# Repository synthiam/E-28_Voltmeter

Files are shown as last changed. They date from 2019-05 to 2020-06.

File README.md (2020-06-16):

# E-28 Voltmeter

**Project Status:** Ready to manufacture

If you are new to GitHub and would like to create a derivative of this project, please have a look at GitHub instructions to [fork a repo](https://help.github.com/en/articles/fork-a-repo)

## Description

Out of our passion to solve the issue of time waste in the robot creation process, ARC was born. The ARC software platform reduces the time it takes to get from idea to implementation. Since 2011 we have been listening to the challenges robot builders encounter and continue to provide them with an ever expanding toolbox of solutions. Join us on this journey!

We didn't stop at the software, we also made time saving hardware solutions. This Voltmeter reference design is one of them. The Voltmeter connects to an ADC port. An ARC ADC skill can take the analog data and convert it into voltage in order to measure the source voltage of a supply or signal. A unique feature of this design is that it has reverse polarity protection. We want to share these files with you so you can create your own version for your community and customers to enjoy!

**Features:** 
- Multimeter Lead input with Flexible silicone wire
- Reverse polarity protection
- PCB can alternately be used with Banana Jacks
- Green Power LED
- Voltage requirement: 0-17.5VDC input
- Wire Length: 34"
- Dimensions: 26.3(W) x 30.8(L) x 9.2(H) (mm) PCB
- Weight: 58g

**Major components:** 
- D2275 Set of Multimeter probes
- 1N4448W-TP 75V 250mA reverse polarity Diode (low leakage current)

**Manufacturing notes:** 
1. Manufacturer: Single side placement and soldering of SMT components
2. Manufacturer: Single Side soldering of THT components

## Contents

[**Documentation:**](https://github.com/synthiam/E-28_Voltmeter/tree/master/E-28%20Documentation) Schematic PDF, BOM

[**Hardware:**](https://github.com/synthiam/E-28_Voltmeter/tree/master/E-28%20Hardware) Altium PCB design File, Altium SCH Design File, Gerbers

*Altium Libraries are also available <a href="https://github.com/synthiam/Synthiam_Altium_Librairies">here</a>*

## Photos

<p align="left">

</p>

## Roll Out Video

This Roll Out video includes:

1. Feature set 
2. Hook-up guide 
3. Using ARC Skills
4. Schematic overview
5. Bill of Materials (BOM) overview
6. Assembly instructions

Link: https://youtu.be/czC40y7L5Ys

 

## ARC Skill

The ARC ADC skills are very easy to use with the Voltmeter. Read or graph the voltage values with the simple click of a mouse button or with code. 

Link: https://synthiam.com/Products/Controls/Adc



## Contact

For profit use of these files requires written consent. Contact partners@synthiam.com. For everyone else, party on!

For support check out our Synthiam Community: https://synthiam.com/Community

## License

This project is released under the following license:

**Hardware:** Creative Commons Plus Attribution-NonCommercial 4.0 International (CC+ BY-NC 4.0)

Please see [LICENSE.md](https://github.com/synthiam/E-28_Voltmeter/blob/master/LICENSE.md) for license details.



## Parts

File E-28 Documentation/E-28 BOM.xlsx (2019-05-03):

Qty | Description | Manufacturer Part No. | Alternative | Designator | Custom Information | Link
E-28 Voltmeter
1 | 2 layer, Blue soldermask, White silkscreen, ENIG | Voltmeter Board |  | PCB
1 | 10Kohm 0603 Resistor 1% | RC0603FR-0710KL |  | R2
1 | 680ohm 0603 Resistor 1% | RC0603JR-07680RL |  | R1
1 | 2.4kohm 0603 Resistor 1% | RC0603FR-072K4L |  | R3
1 | 75V 250mA reverse polarity Diode SOD123 (low leakage current) | 1N4448W-TP |  | D1 |  | https://www.digikey.ca/product-detail/en/micro-commercial-co/1N4448W-TP/1N4448WTPMSCT-ND/789337
1 | Set of Multimeter probes | D2275 | F85 | P2, P3 | Banana connectors on probes need to be removed and wires directly soldered to board | https://www.alibaba.com/product-detail/Multimeter-Probe-DMM-Test-Probes-Multimetro_62021861221.html
1 | LED Green Clear 0805 | QBLP631-IG |  | LED
1 | 3 position 2.0mm pitch JST-PH header | S3B-PH-SM4-TB(LF)(SN) |  | P1 |  | https://www.digikey.ca/product-detail/en/jst-sales-america-inc/S3B-PH-SM4-TB-LF-SN/455-1750-1-ND/926847
4 | 8mm x 2.5mm self adhesive rubber feet (clear) |  |  |  | Placed on the bottom of the board in the 4 corners

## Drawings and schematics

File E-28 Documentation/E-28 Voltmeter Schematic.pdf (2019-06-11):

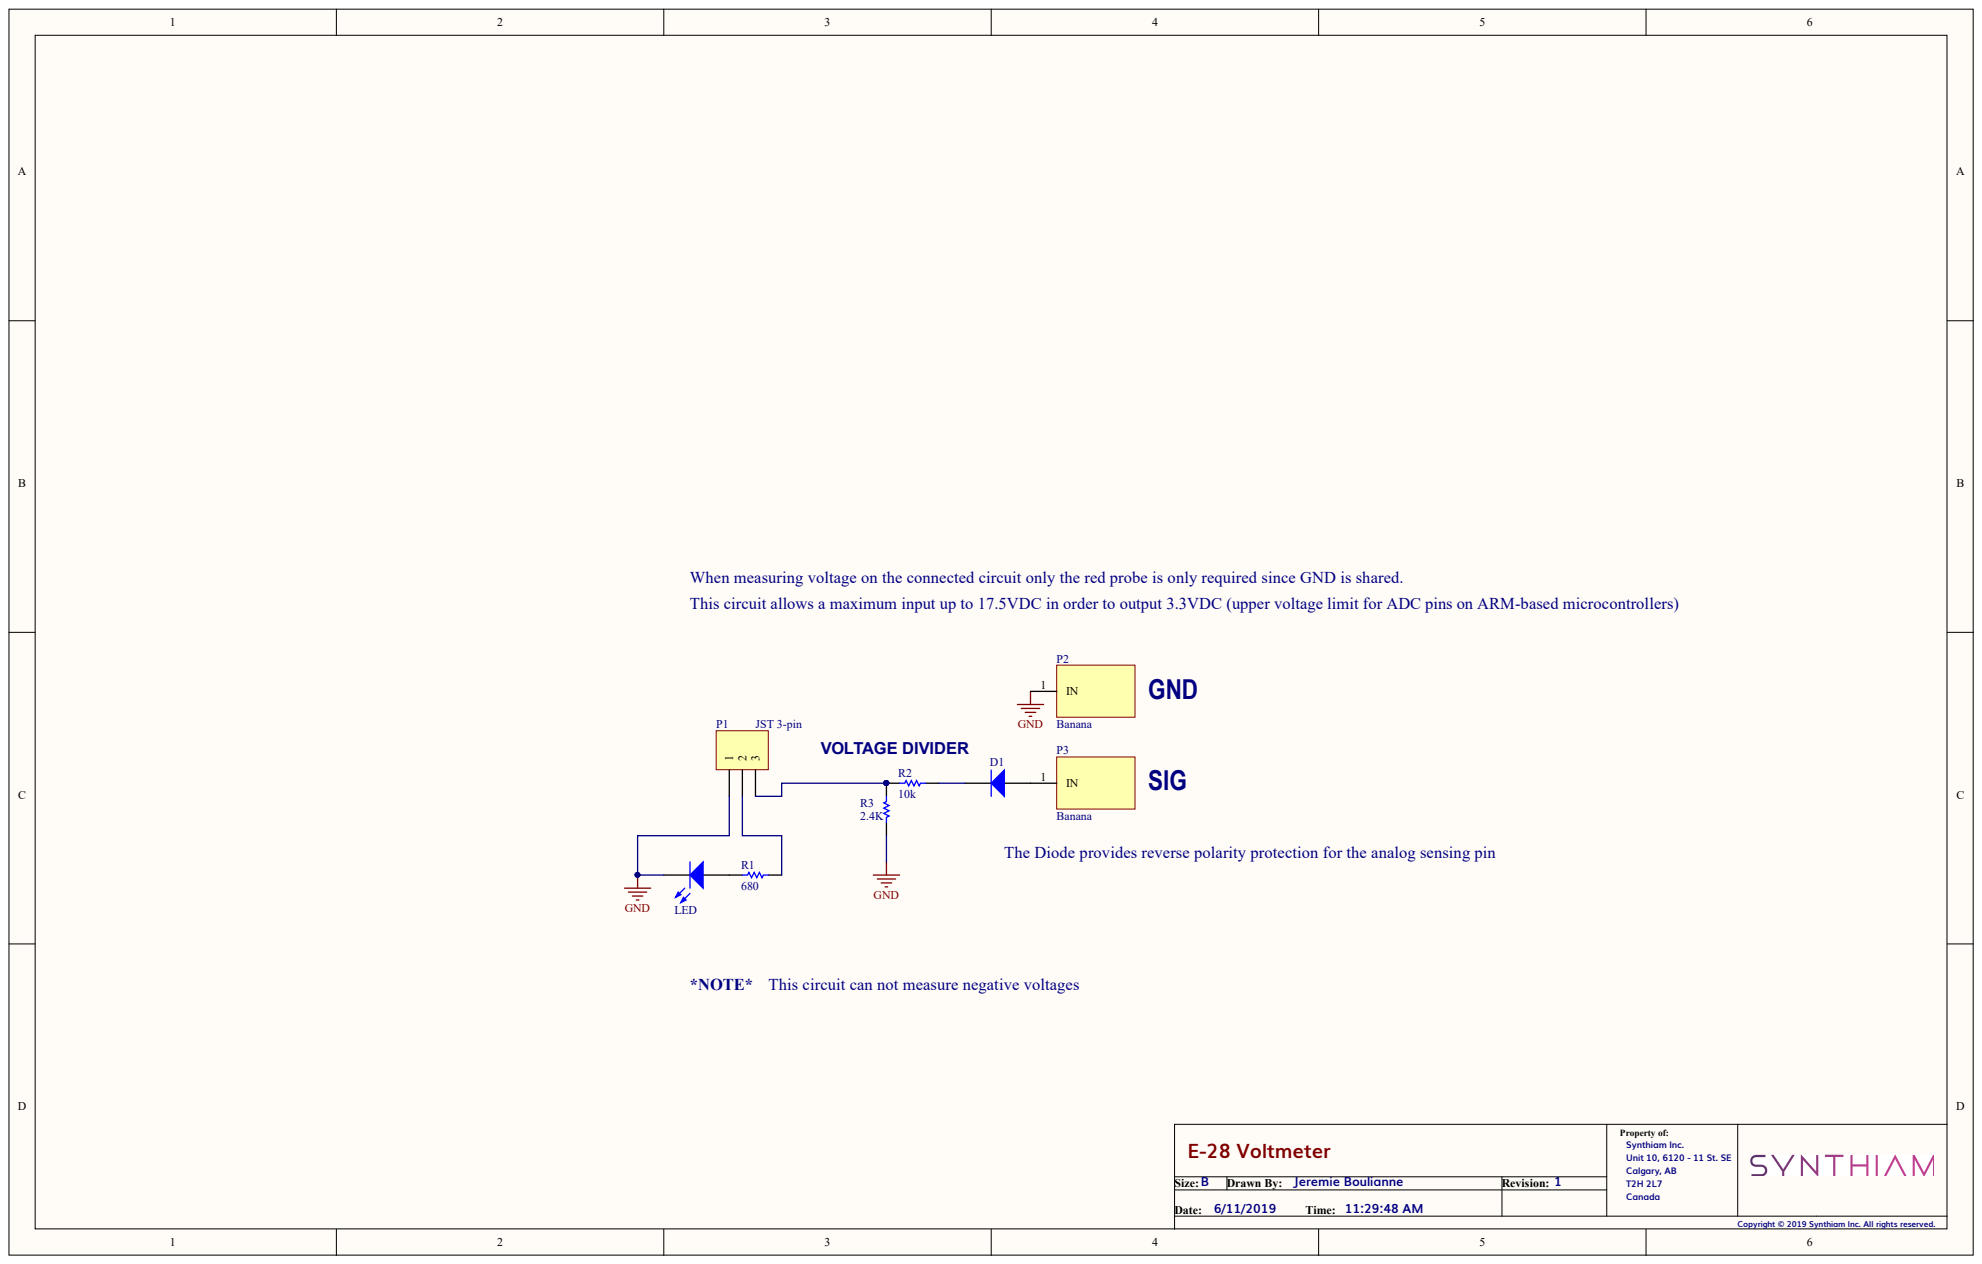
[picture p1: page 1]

When measuring voltage on the connected circuit only the red probe is only required since GND is shared.
This circuit allows a maximum input up to 17.5VDC in order to output 3.3VDC (upper voltage limit for ADC pins on ARM-based microcontrollers)

The Diode provides reverse polarity protection for the analog sensing pin

*NOTE* This circuit can not measure negative voltages

E-28 Voltmeter | Property of: Synthiam Inc. Unit 10, 6120 - 11 St. SE Calgary, AB T2H 2L7 Canada

B Size: | Jeremie Boulianne Drawn By: | 1 Revision:
6/11/2019 11:29:48 AM Date: Time:

Copyright © 2019 Synthiam Inc. All rights reserved.

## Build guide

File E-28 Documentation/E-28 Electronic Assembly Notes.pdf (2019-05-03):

# Electronic Assembly Notes

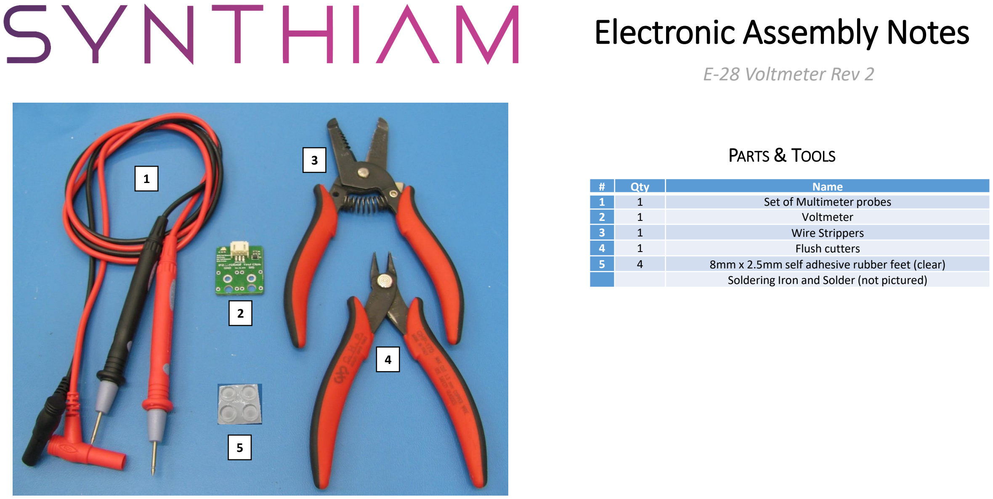
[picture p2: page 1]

# | Qty | Name

1 | 1 | Set of Multimeter probes
2 | 1 | Voltmeter
3 | 1 | Wire Strippers
4 | 1 | Flush cutters
5 | 4 | 8mm x 2.5mm self adhesive rubber feet (clear)
| | Soldering Iron and Solder (not pictured)

E-28 Voltmeter Rev 2

PARTS & TOOLS

1

2

3

4

5

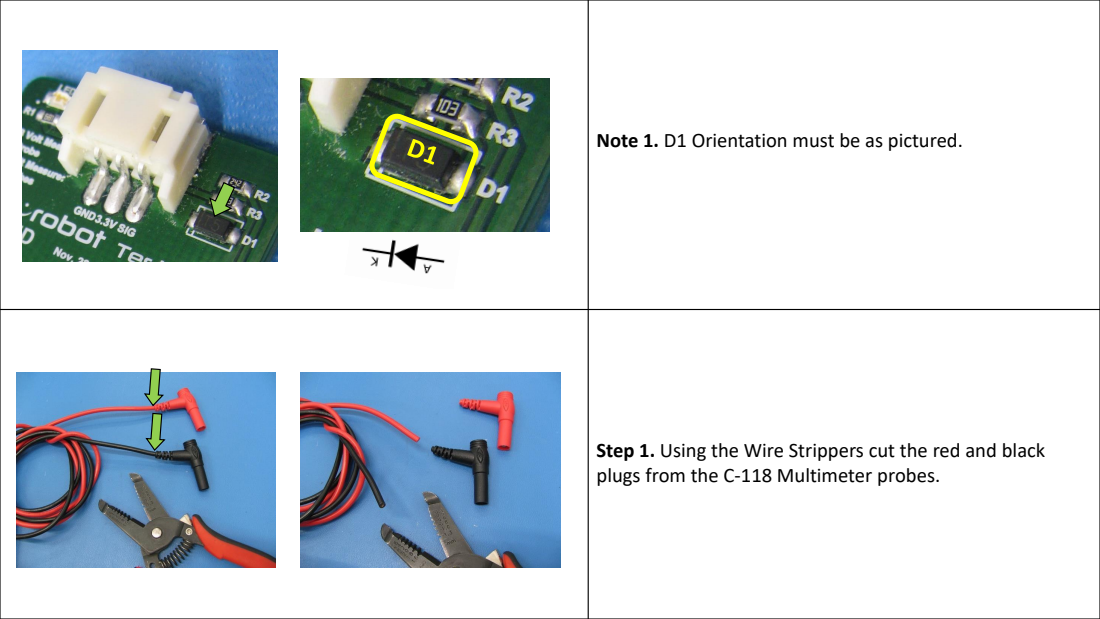
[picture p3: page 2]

Note 1. D1 Orientation must be as pictured.

Step 1. Using the Wire Strippers cut the red and black
plugs from the C-118 Multimeter probes.

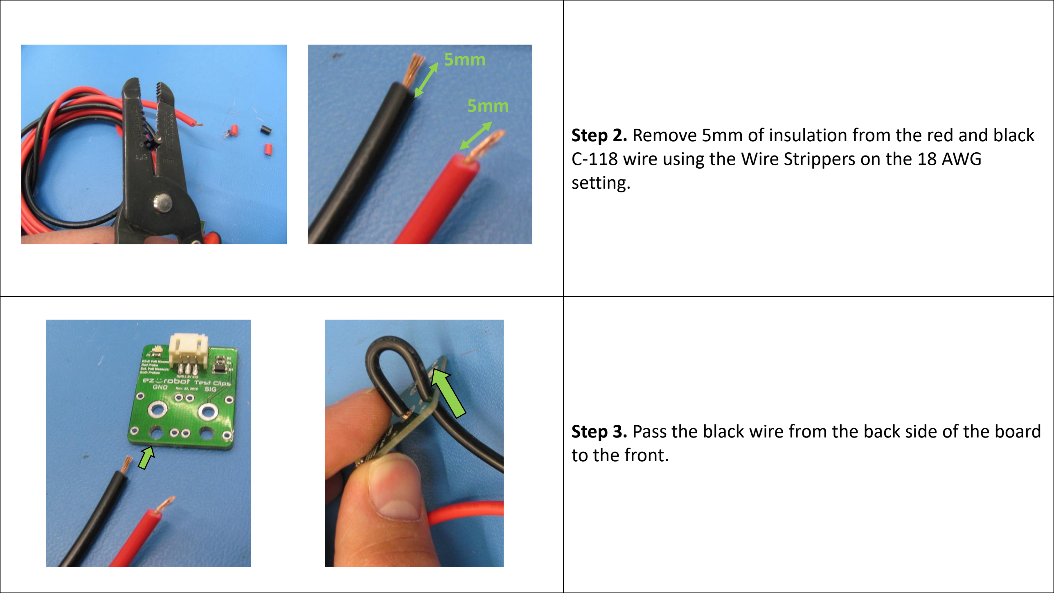
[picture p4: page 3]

Step 2. Remove 5mm of insulation from the red and black C-118 wire using the Wire Strippers on the 18 AWG setting.
Step 3. Pass the black wire from the back side of the board to the front.

5mm

5mm

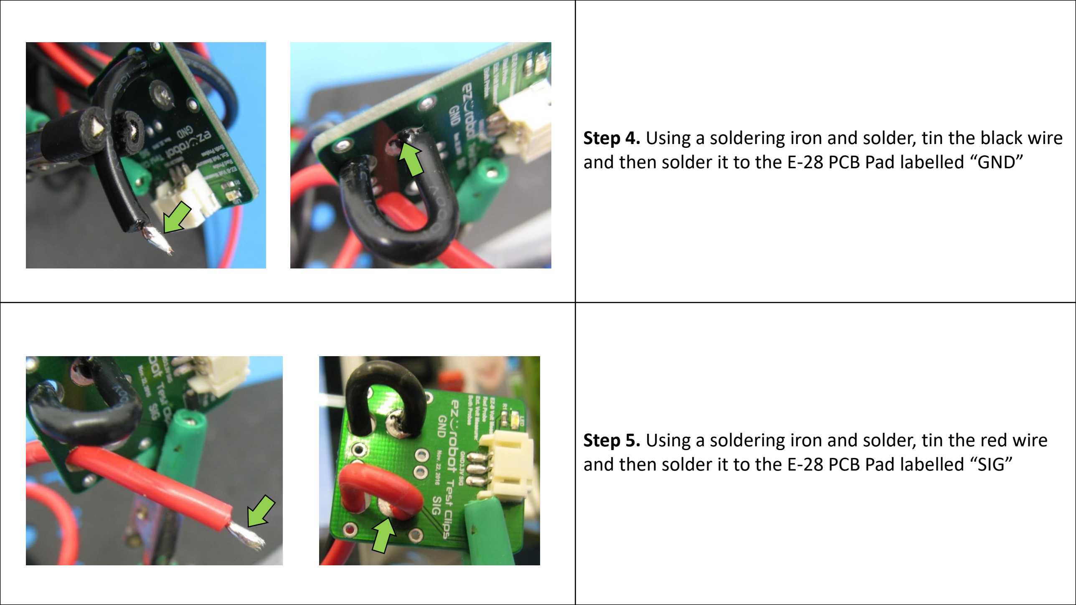
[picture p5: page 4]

Step 4. Using a soldering iron and solder, tin the black wire and then solder it to the E-28 PCB Pad labelled “GND”
Step 5. Using a soldering iron and solder, tin the red wire and then solder it to the E-28 PCB Pad labelled “SIG”

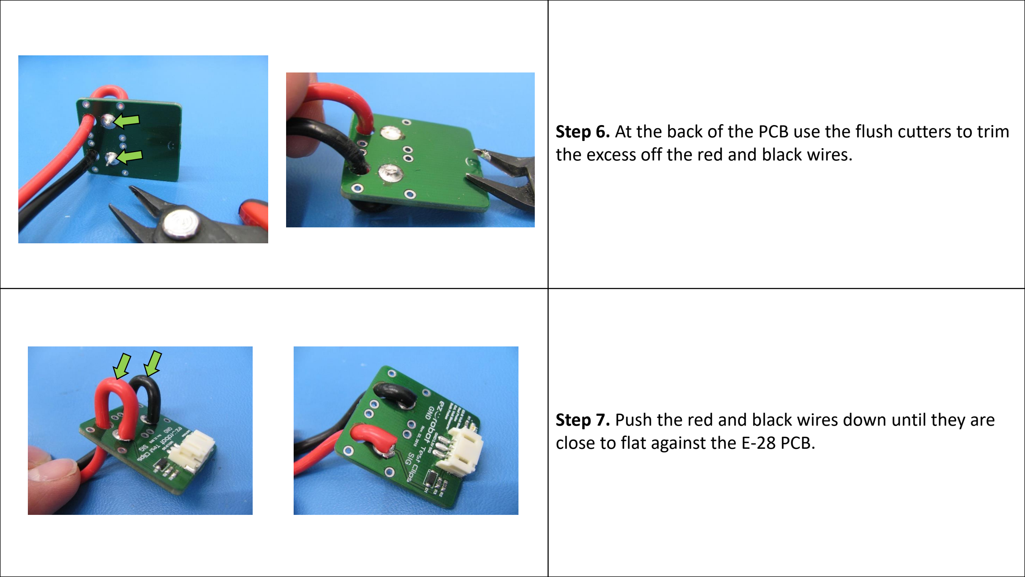
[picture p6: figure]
the excess off the red and black wires.; close to flat against the E-28 PCB.

Step 6. At the back of the PCB use the flush cutters to trim
Step 7. Push the red and black wires down until they are

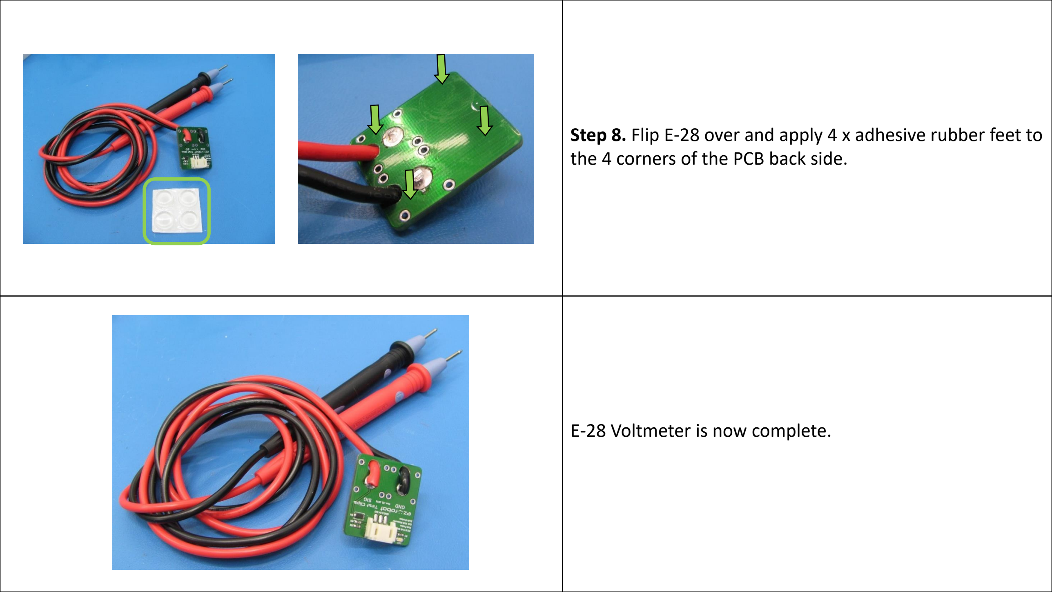
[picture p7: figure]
the 4 corners of the PCB back side.; E-28 Voltmeter is now complete.

Step 8. Flip E-28 over and apply 4 x adhesive rubber feet to

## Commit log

2019-06-11 Updated the Voltmeter PCB, schematic, and gerbers
    Changed the position of Diode D1 in order to have a more linear output.
    [E-28 Voltmeter.PcbDoc, E-28 Voltmeter.SchDoc]
2019-06-11 updated Schematic
